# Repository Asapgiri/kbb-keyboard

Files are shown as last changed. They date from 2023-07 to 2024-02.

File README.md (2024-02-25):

# Keyboard by KBB

## Summary
We are making this keyboard for self improvement and fun. The 65% mechanical keyboard has it's original PCB design, case and plate model.

## To open the shematics and PCB design
The PCB design was created in KiCad, so you can open it in the `kicad/default` folder.

## To run the code
You only need to upload the code once using Arduino IDE.

Keep in mind, that first the Atmega32u4 will need a bootloader, witch is programmed trough the bootloader pins. We had to program it with an Esp32-C3-mini, witches Arduino ISA codes I will upload here under the folder `Esp32-ISA`.

## Dependencies
Place the dependencies into the lib folder.
Desktop Utility:
--> simple_serial_port https://github.com/dmicha16/simple_serial_port/tree/master

## Layout
keyboard-layout
In this image the different colors mean the segmentation of the keys with muxes.
You can currently only see the details in Schematic and the Code files.

## Function keys
### Supported
| Combination | Meaning  | | Combination | Meaning  | | Combination | Meaning  |
| --- | --- | --- | --- | --- | --- | --- | --- |
| FN + 1 | F1 | | FN + 7 | F7 | | FN + INS | PRT SCR  |
| FN + 2 | F2 | | FN + 8 | F8 | | FN + WIN | WIN LOCK |
| FN + 3 | F3 | | FN + 9 | F9 | | FN + -> | FN LOCK  |
| FN + 4 | F4 | | FN + 0 | F10 | | FN + ALT | MENU |
| FN + 5 | F5 | | FN + - | F11 | | FN + ESC | ` |
| FN + 6 | F6 | | FN + = | F12 | | FN + SHIFT + ESC | ~ |

### Under develpement
These keys are yet not supported due to the incompatibility of `Keyboard.h`.
| Combination | Meaning |
| --- | --- |
| FN + ; | PREV MUSIC  |
| FN + \ | NEXT  MUSIC |
| FN + , | VOLUME DOWN |
| FN + . | VOLUME UP |
| FN + / | PLAY |
| FN + END | SLEEP |

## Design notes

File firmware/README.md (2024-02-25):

# Read before building!

Before you can build the project, first you have to install the arduino libraries.

## Run the following command if you are on linux:
```sh
sudo apt install arduino clang lld cmake
sudo snap install arduino-cli
```
if you install `arduino-cli` with a different method, then change the path to `.arduino15` folder in `ARDUINO_PATH`
cmake variable in `toolchain/avr.toolchain.cmake`.

## After installation, run the avr initalization:
```sh
arduino-cli core install arduino:avr --verbose
```

# To build, first initialize the subdirectories, then build the project with cmake
```
git submodule init
```

To build in the `build` directoriy:
```
cmake -S. -Bbuild -D CMAKE_TOOLCHAIN_FILE=toolchain/leonardo.toolchain.cmake
cmake --build build -j -t kbb_keyboard
```

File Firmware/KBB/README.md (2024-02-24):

# Read before building!

Before you can build the project, first you have to install the arduino libraries.

## Run the following command if you are on linux:
```
sudo apt install arduino clang lld cmake
```

## After installation, you need to run the newly installed Arduino IDE to install the basic AVR libraries fro building:

Under `Tools > Board > Board Manager`.

# To build, first initialize the subdirectories, then build the project with cmake
```
git submodule init
```
To build in the `build` directoriy:
```
cmake -S. -Bbuild -D CMAKE_TOOLCHAIN_FILE=Arduino-AVR-CMake/cmake/toolchain/leonardo.toolchain.cmake
cmake --build build -j -t kbb_keyboard
```

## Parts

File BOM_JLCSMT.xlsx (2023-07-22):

Comment | Designator | Footprint | JLCPCB Part #（optional）
5V Zener | D4 | D_SOD-523 | C151368
100nF | C5,C15,C9,C10,C8,C14,C13,C12,C7,C11,C6 | C_0402_1005Metric | C1525
R22 | R8,R7 | R_0402_1005Metric | C409710
220pF | C17,C22,C16,C23,C21,C20,C18,C19 | C_0402_1005Metric | C114401
USB_C_Receptacle_USB2.0 | J1 | USB_C_Receptacle_G-Switch_GT-USB-7010ASV | C5178539
U74HC4051G-Q16 | MUX6,MUX3,MUX1,MUX7,MUX4,MUX2,MUX5,MUX8 | QFN-16-1EP_3x3mm_P0.5mm_EP1.7x1.7mm | C2848707
R10K | R18,R15,R9,R13,R17,R16,R12,R11,R14 | R_0402_1005Metric | C176119
R1M | R6 | R_0603_1608Metric | C2889400
5.11K | R20,R2,R19,R1 | R_0402_1005Metric | C911893
2pF | C2,C3 | C_0402_1005Metric | C147348
1uF | C1 | C_0402_1005Metric | C913556
R330 | R5,R3,R4 | R_0402_1005Metric | C186314
7F16000E09UCG | Y1 | Crystal_SMD_7F16000E09UCG_4pin | C252269
PMOS | Q1 | TO-252-2 | C558296
R100K | R10 | R_0402_1005Metric | C407753
ATmega32U4-M | U1 | QFN-44-1EP_7x7mm_P0.5mm_EP5.2x5.2mm | C112161
10uF | C4 | C_0402_1005Metric | C466623
PG151101S11 | S48,S6,S21,S31,S51,S20,S65,S2,S26,S64,S12,S27,S46,S18,S43,S47,S63,S62,S9,S40,S34,S19,S25,S30,S23,S5,S37,S17,S60,S36,S49,S3,S11,S7,S45,S44,S38,S1,S67,S39,S50,S33,S61,S16,S10,S22,S4,S35,S24,S52,S66,S32,S13,S8 | SW_Cherry_MX_1.00u_PCB | C400239
PG151101S12 | S57 | SW_Cherry_MX_6.25u_PCB | C400239
PG151101S13 | S54,S59,S58,S55,S56 | SW_Cherry_MX_1.25u_PCB | C400239
PG151101S14 | S14 | SW_Cherry_MX_2.00u_PCB | C400239
PG151101S15 | S42,S41 | SW_Cherry_MX_2.25u_PCB | C400239
PG151101S16 | S15,S28 | SW_Cherry_MX_1.50u_PCB | C400239
PG151101S17 | S29,S53 | SW_Cherry_MX_1.75u_PCB | C400239

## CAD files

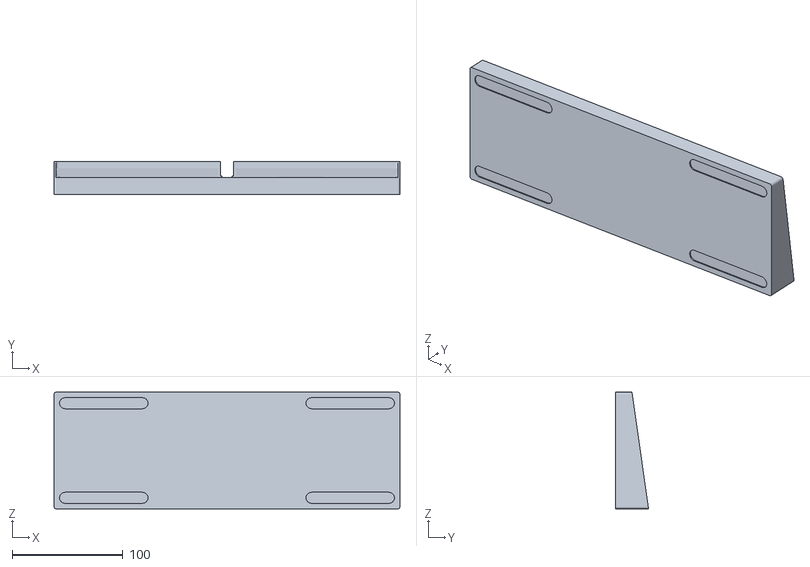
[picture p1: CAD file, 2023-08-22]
case_design/Inventor/stl/case_in_one_full_remake.stl
312.9 x 30.0 x 105.5

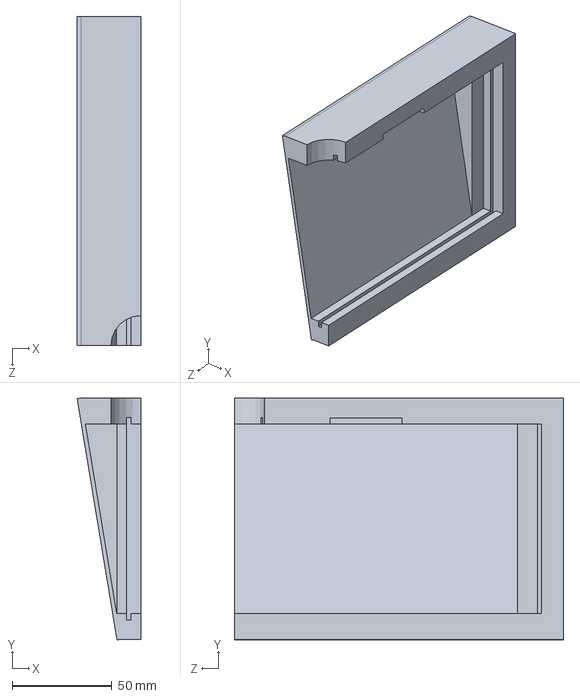
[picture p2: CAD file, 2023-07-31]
case_design/SBVersions/Beta 0.9/KBB_Keyboard right.SLDPRT
32.0 x 121.3 x 165.0 mm

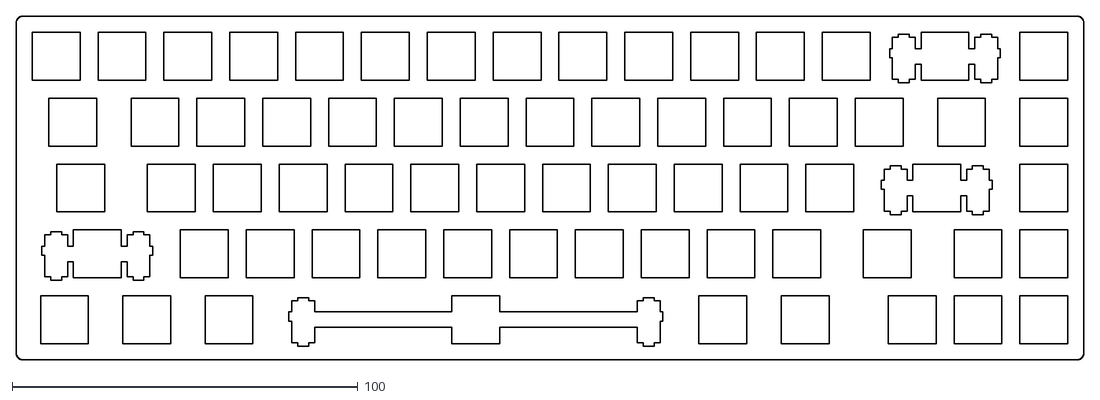
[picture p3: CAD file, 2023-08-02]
plate/plate.dxf
309.0 x 99.4

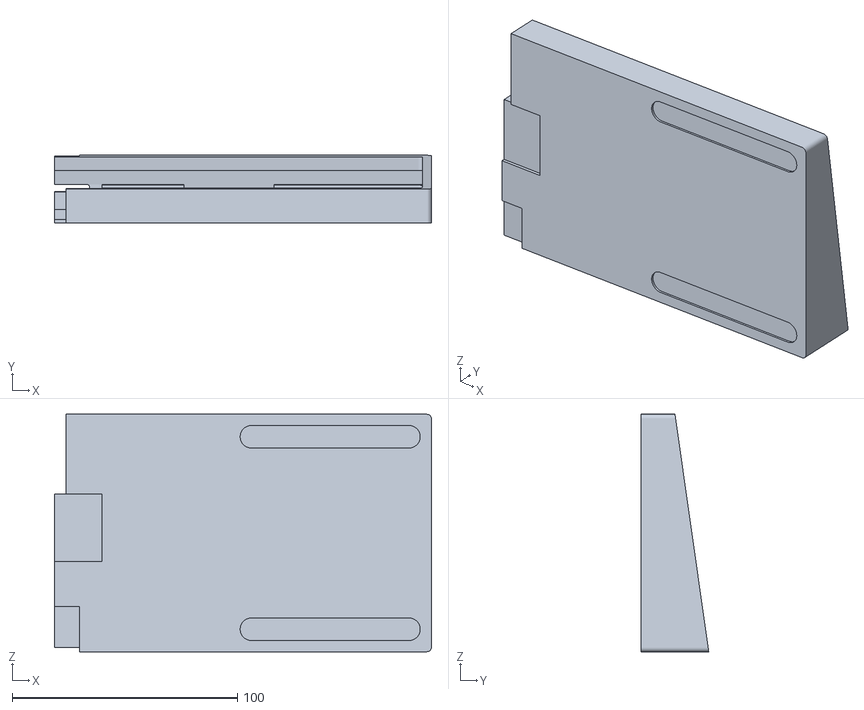
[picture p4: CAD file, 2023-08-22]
case_design/Inventor/stl/case_in_one_p2.stl
167.4 x 30.0 x 105.5

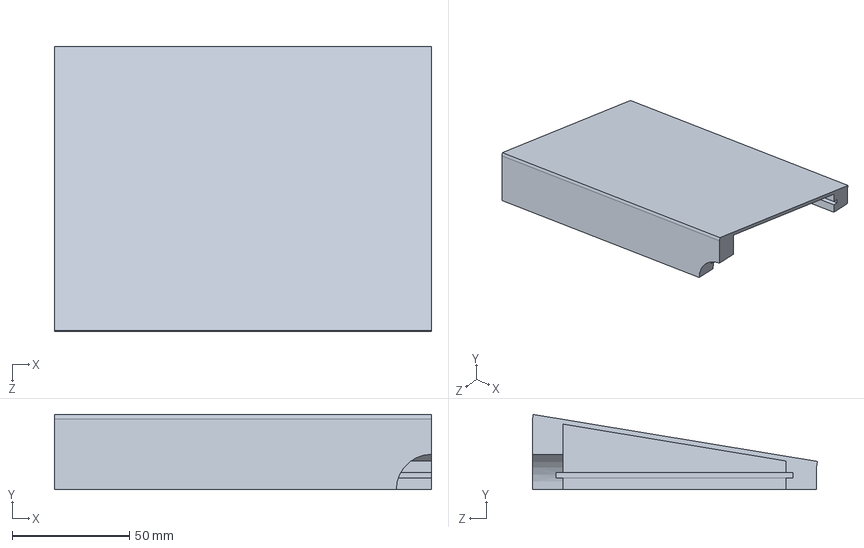
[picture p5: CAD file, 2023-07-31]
case_design/SBVersions/Beta 0.9/KBB_Keyboard left.SLDPRT
160.5 x 32.0 x 121.3 mm

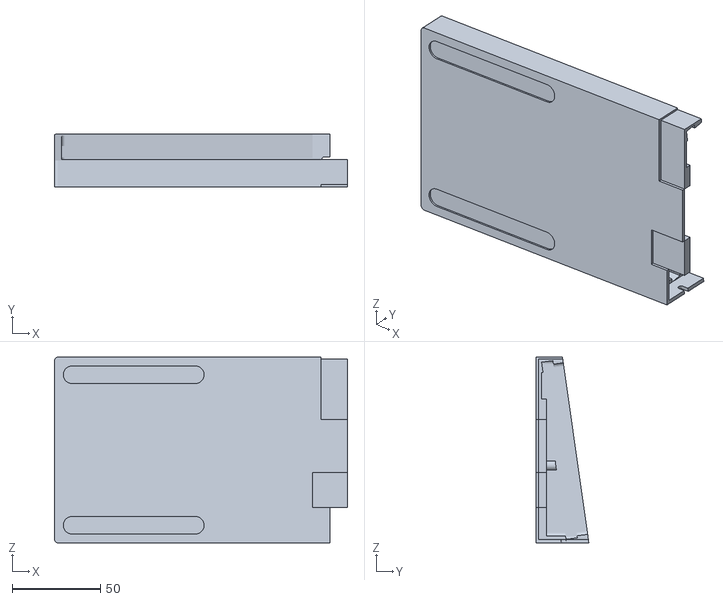
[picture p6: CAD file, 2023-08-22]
case_design/Inventor/stl/case_in_one_p1.stl
166.4 x 30.0 x 105.5

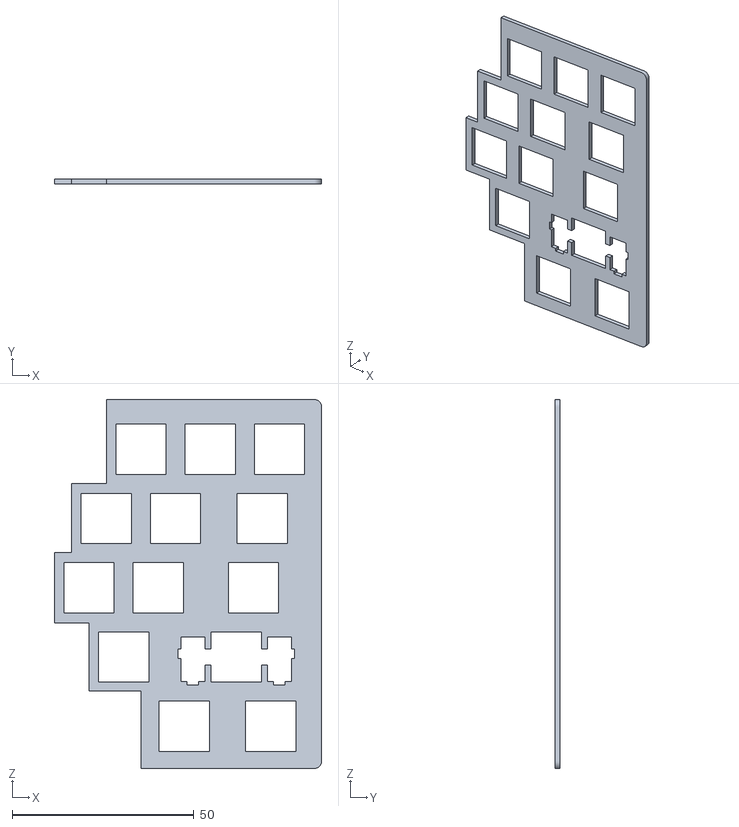
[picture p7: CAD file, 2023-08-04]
case_design/Inventor/stl/case_plate_p3.stl
73.5 x 1.40 x 101.5

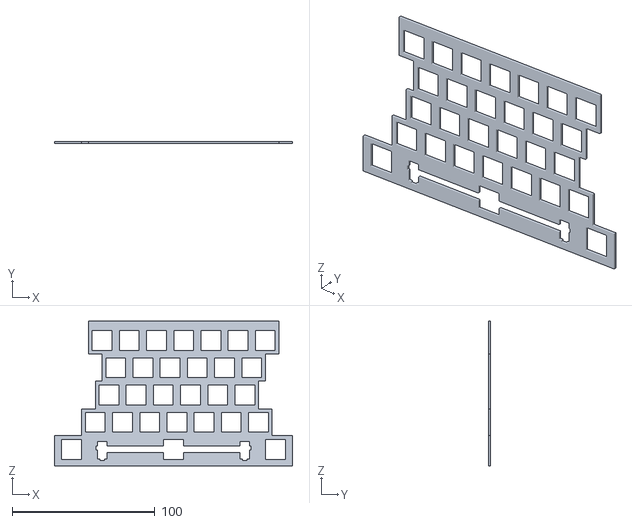
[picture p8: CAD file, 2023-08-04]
case_design/Inventor/stl/case_plate_p1.stl
166.7 x 1.40 x 101.5

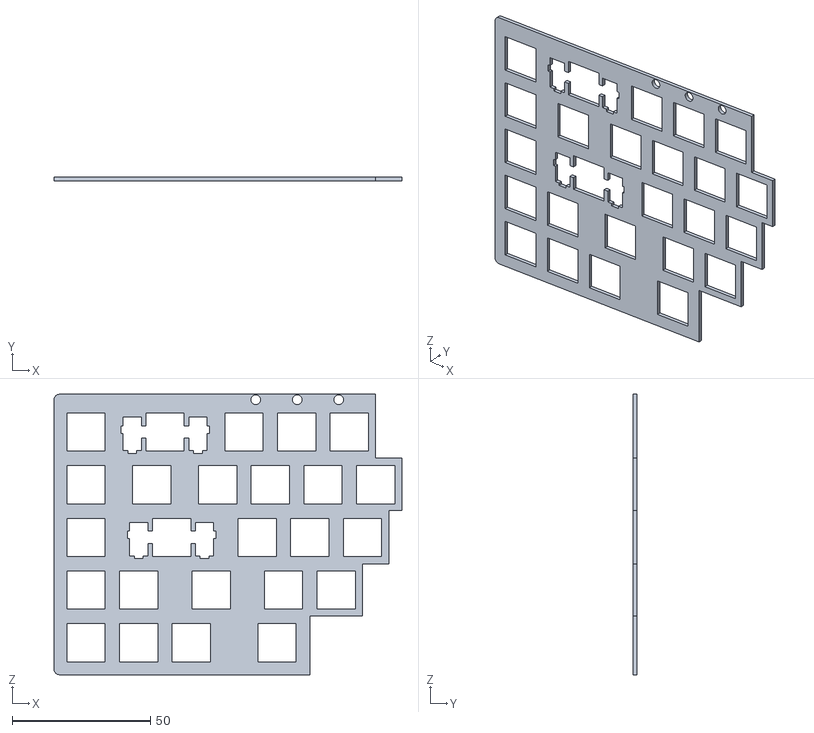
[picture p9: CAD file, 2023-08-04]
case_design/Inventor/stl/case_plate_p2.stl
125.9 x 1.40 x 101.5

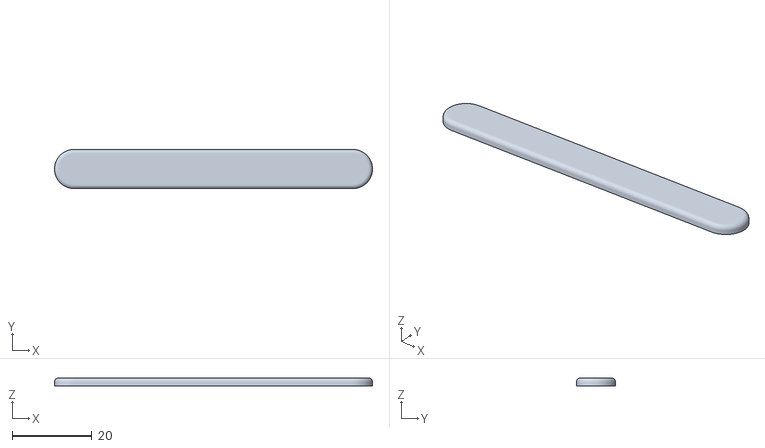
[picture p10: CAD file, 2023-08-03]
case_design/Inventor/stl/foot.stl
79.6 x 9.80 x 2.00

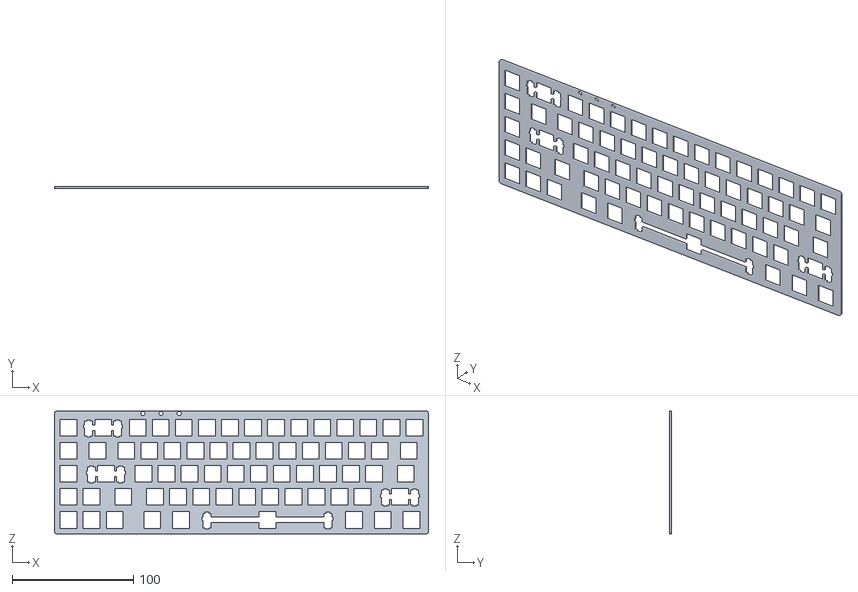
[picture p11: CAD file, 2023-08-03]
case_design/Inventor/stl/case_plate.stl
309.0 x 1.48 x 101.5

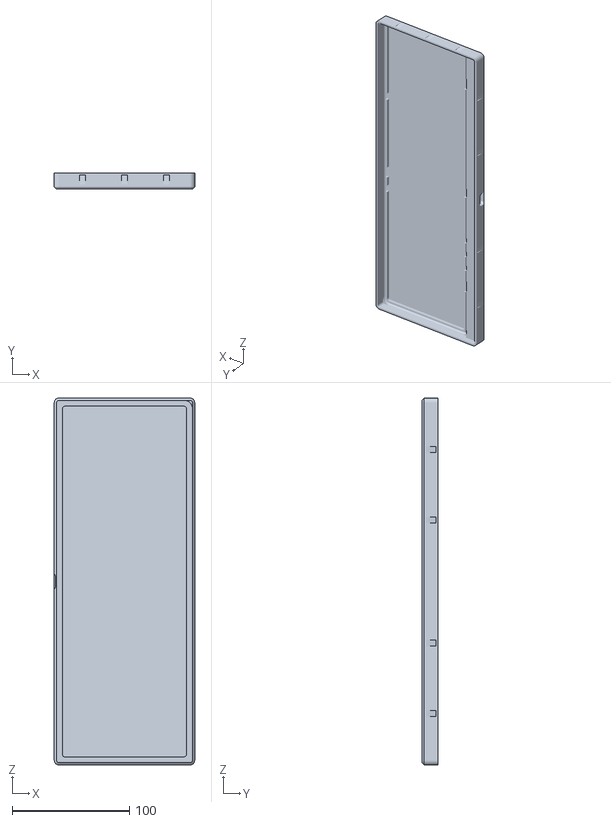
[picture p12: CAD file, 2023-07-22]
case_design/Inventor/stl/case bottom.stl
120.0 x 14.0 x 313.3

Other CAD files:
case_design/Inventor/stl/case_in_one_p2_no_holder.stl
case_design/Inventor/stl/case_in_one_p1_no_holder.stl
case_design/Inventor/stl/case_in_one.stl
case_design/Inventor/OldVersions/case_in_one.0004.ipt
case_design/Inventor/OldVersions/case_plate.0003.ipt
case_design/Inventor/OldVersions/case_plate_p1.0006.ipt
case_design/Inventor/OldVersions/case_plate_p2.0001.ipt
case_design/Inventor/OldVersions/case_plate_p2.0002.ipt
case_design/Inventor/case bottom display.ipt
case_design/Inventor/case bottom.ipt
case_design/Inventor/case top display.ipt
case_design/Inventor/case top.ipt
case_design/Inventor/case_in_one.ipt
case_design/Inventor/case_in_one_full_remake.ipt
case_design/Inventor/case_in_one_p1.ipt
case_design/Inventor/case_in_one_p2.ipt
case_design/Inventor/case_plate.ipt
case_design/Inventor/case_plate_p1.ipt
case_design/Inventor/case_plate_p2.ipt
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

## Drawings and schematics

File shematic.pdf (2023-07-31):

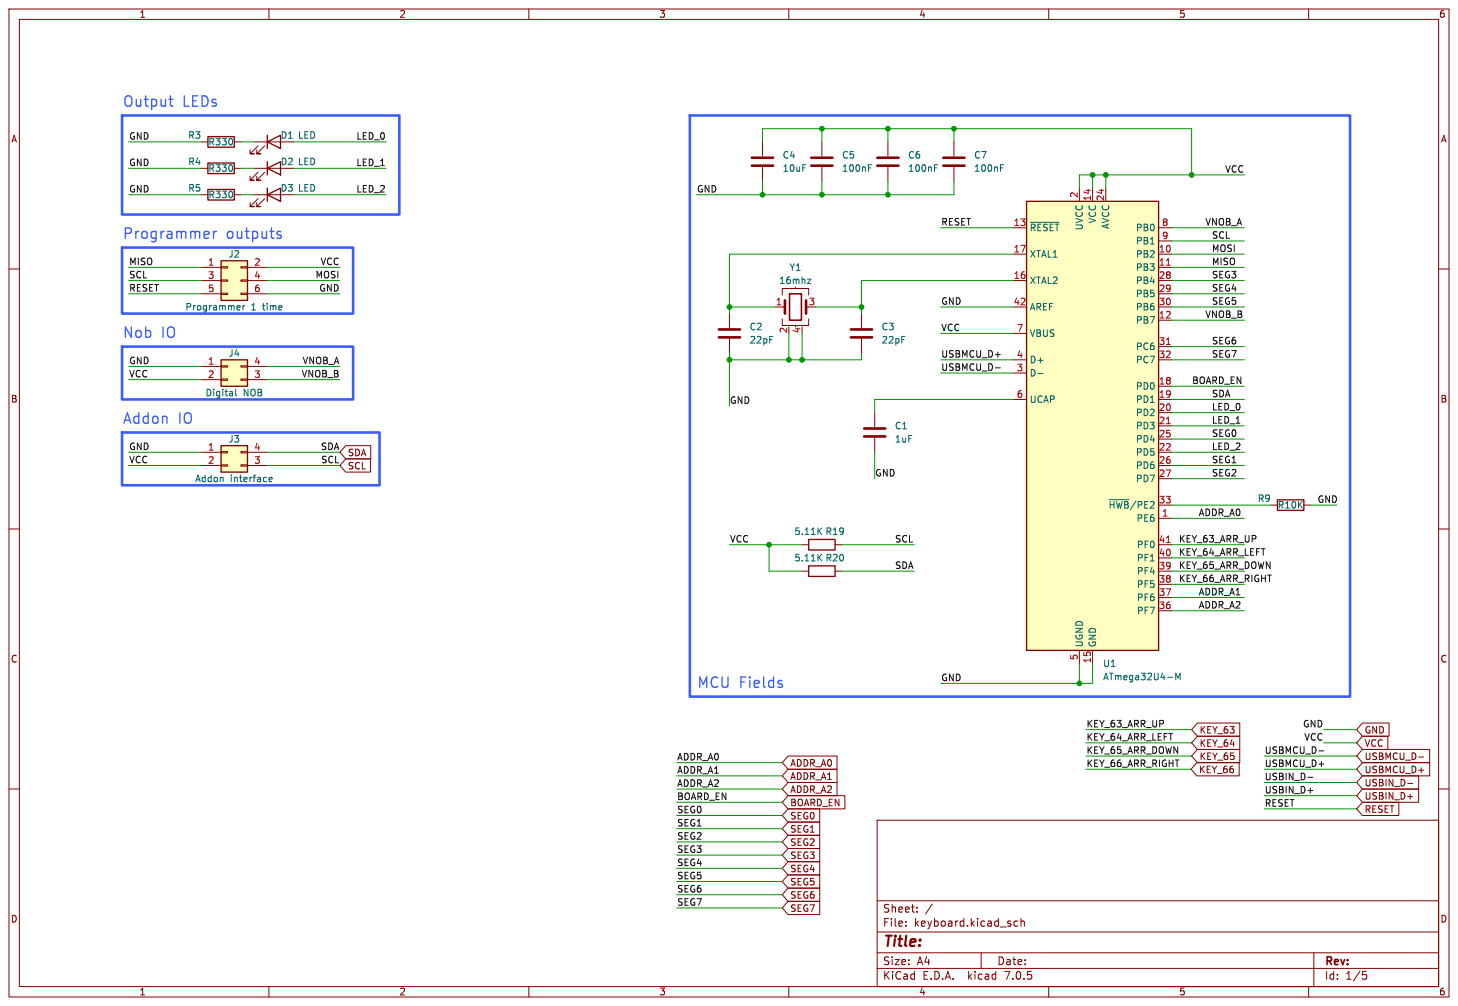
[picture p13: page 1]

Id: 1/5 Title: File: keyboard.kicad_sch Sheet: /

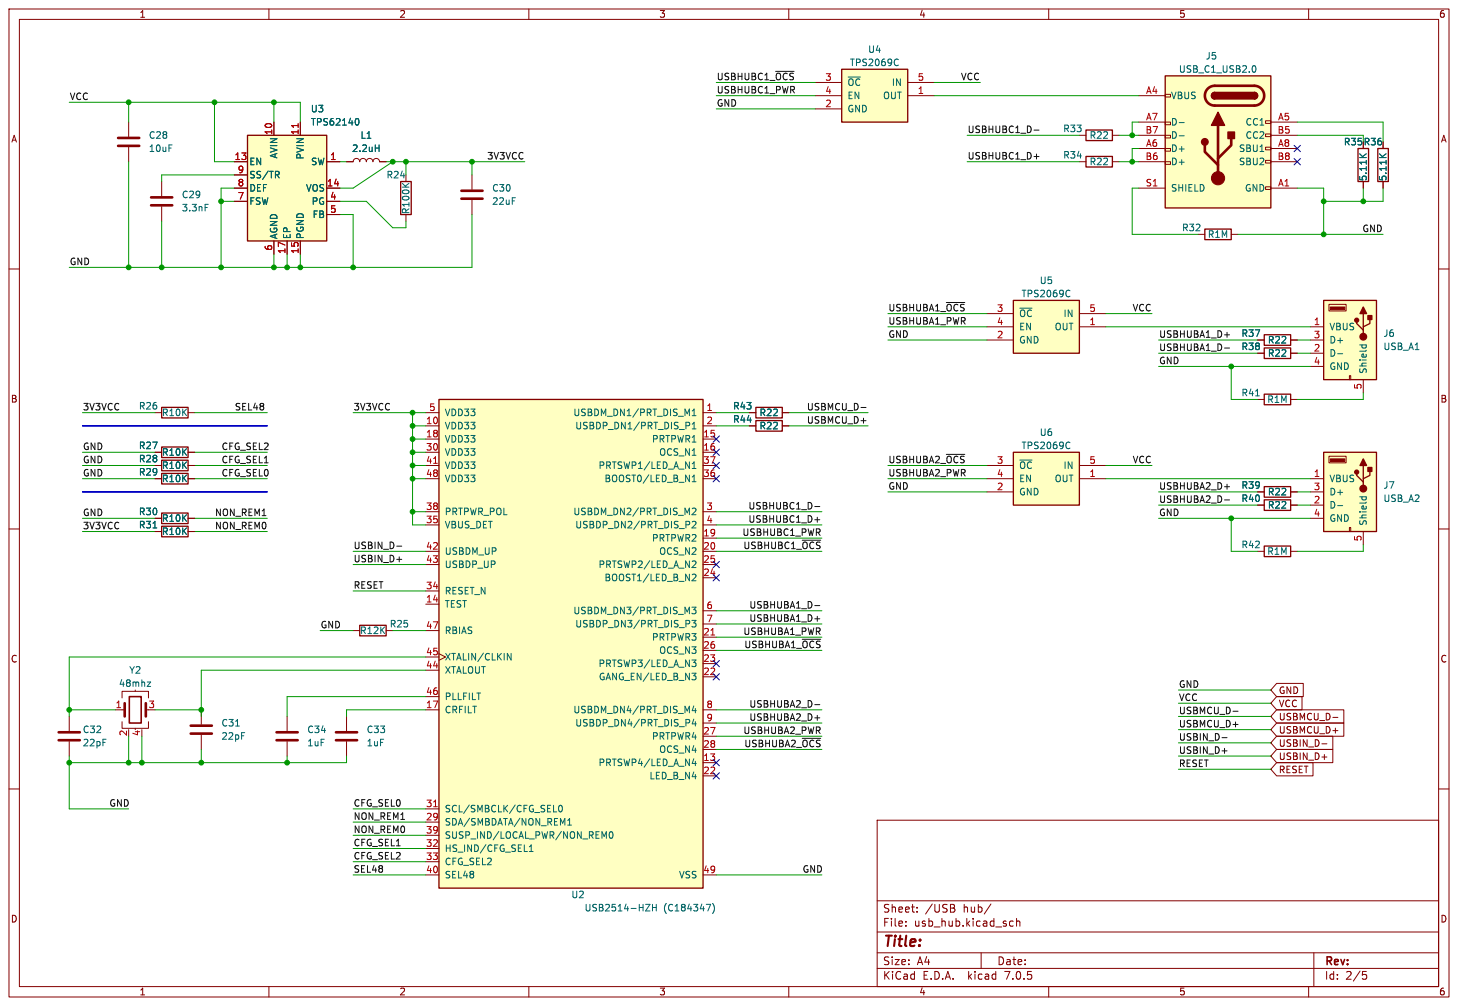
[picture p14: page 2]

6 FSW 7 DEF 8 SS/TR 9 U3 TPS62140 R35 5.11K

6 FSW 7 DEF 8 SS/TR 9 R43 R22

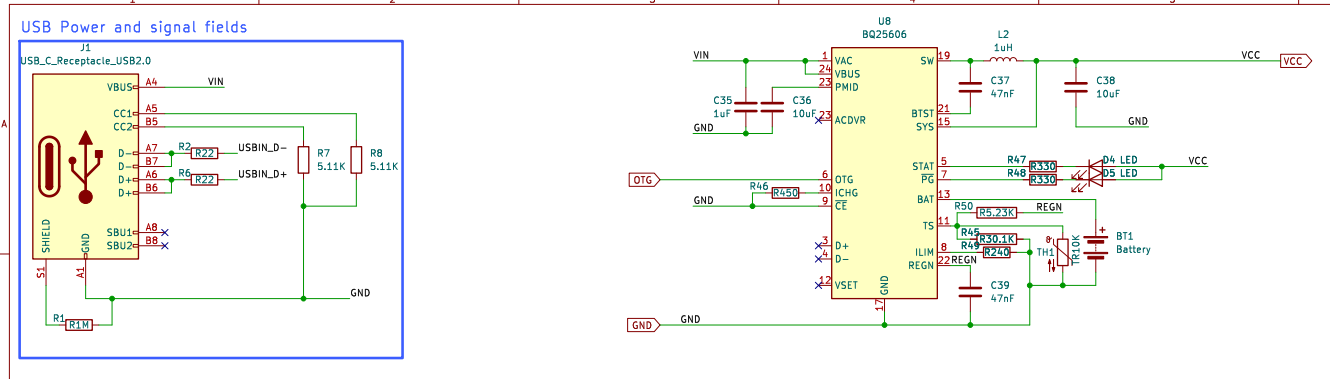
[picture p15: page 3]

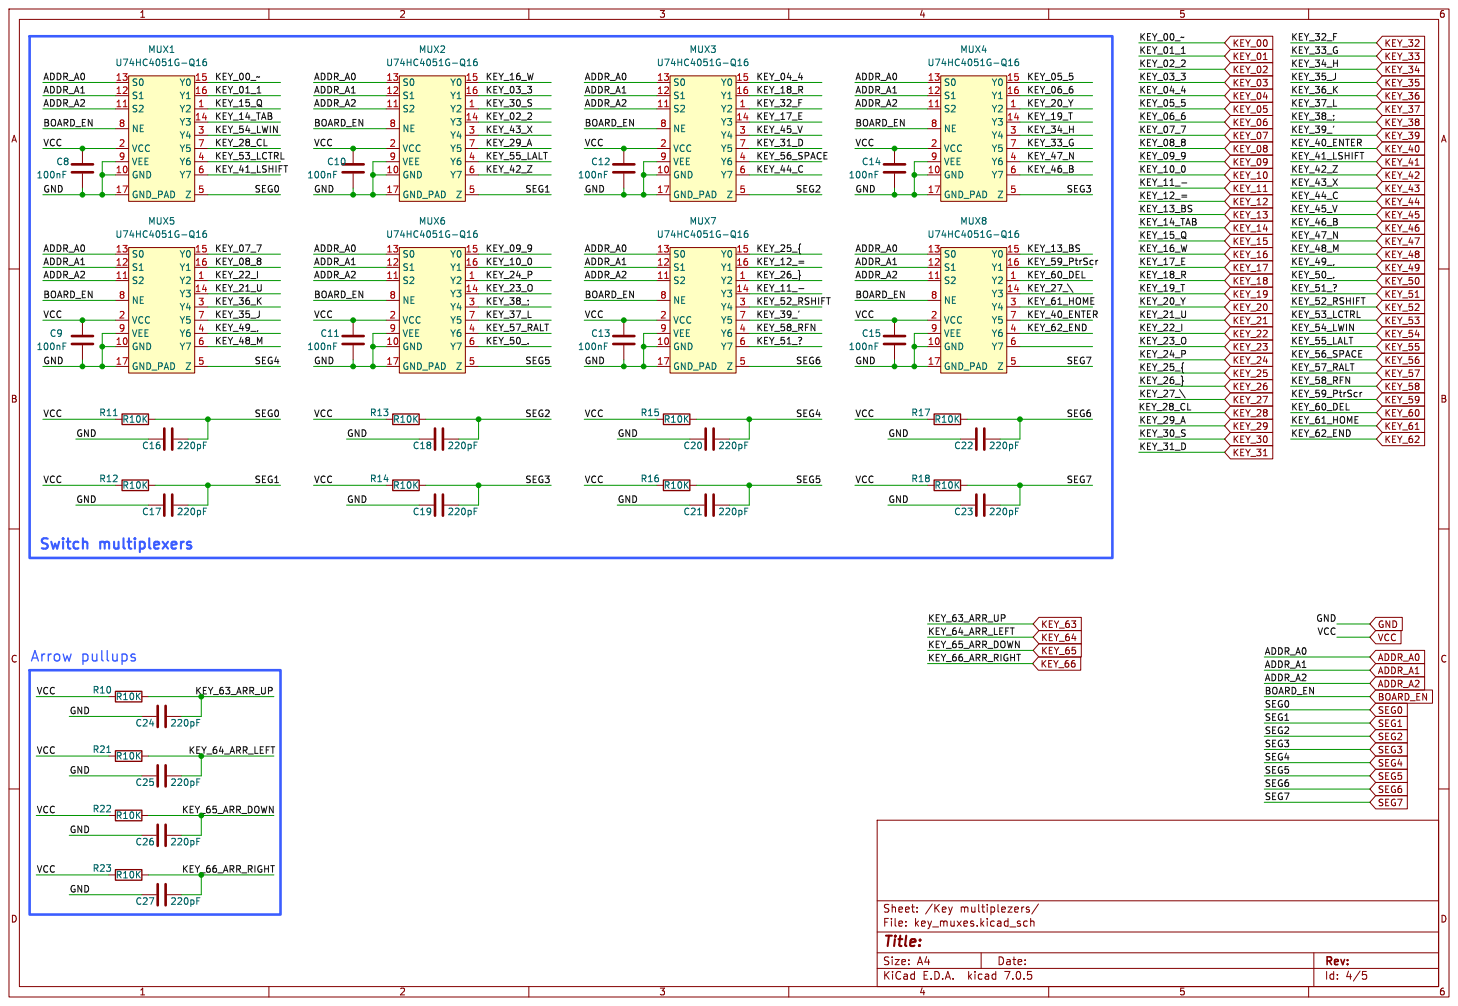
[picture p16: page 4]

Id: 4/5 Title: File: key_muxes.kicad_sch Sheet: /Key multiplezers/

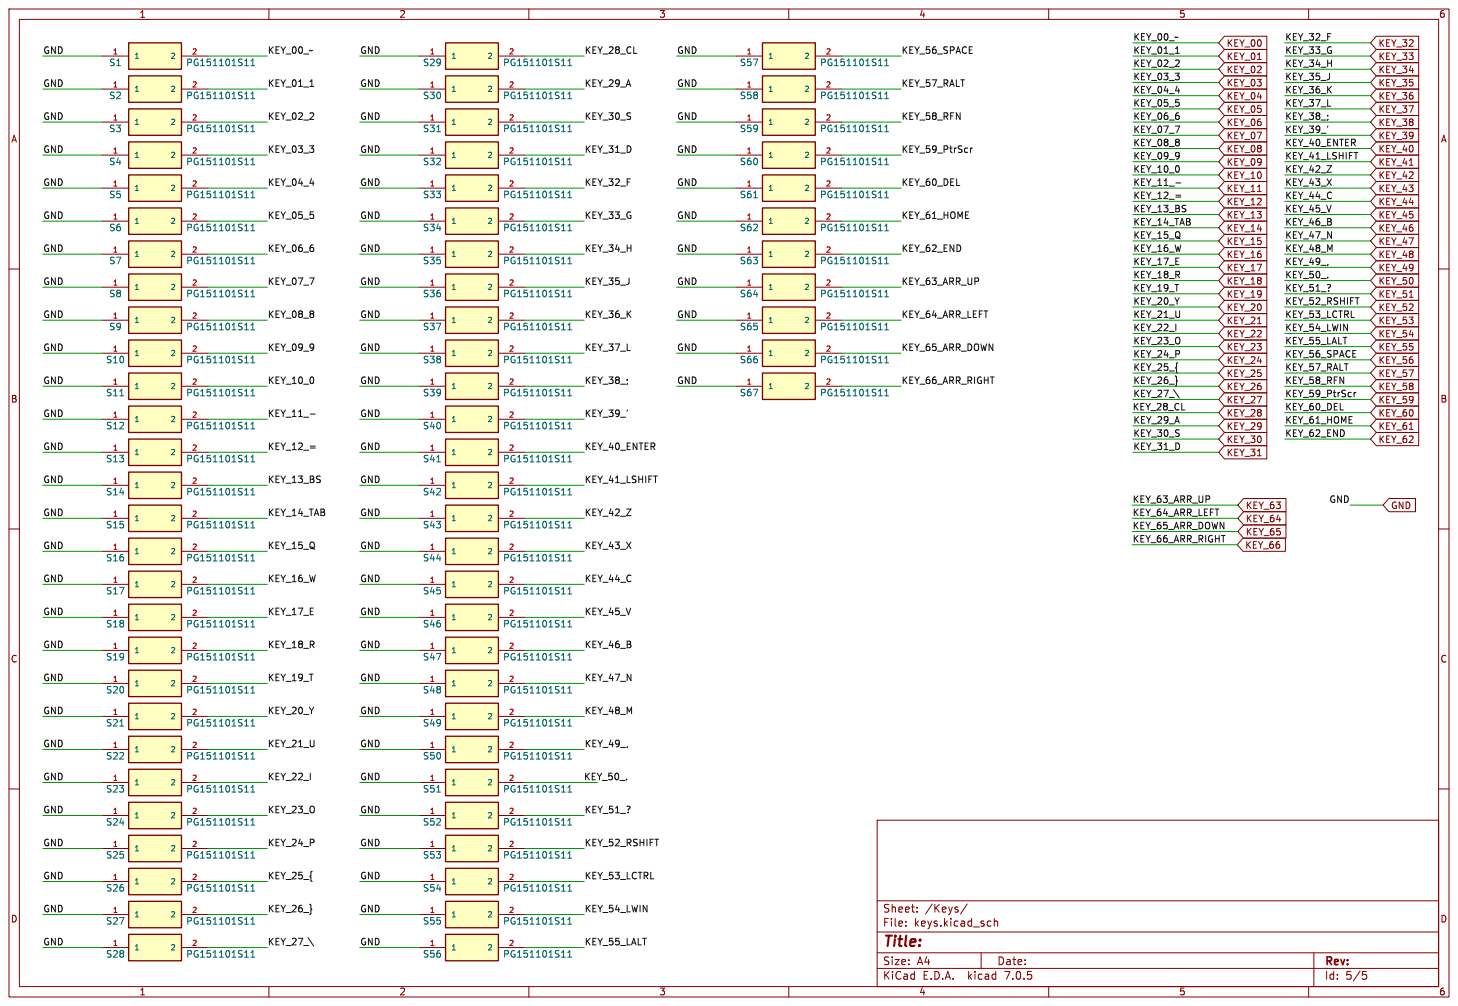
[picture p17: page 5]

GND GND GND GND GND

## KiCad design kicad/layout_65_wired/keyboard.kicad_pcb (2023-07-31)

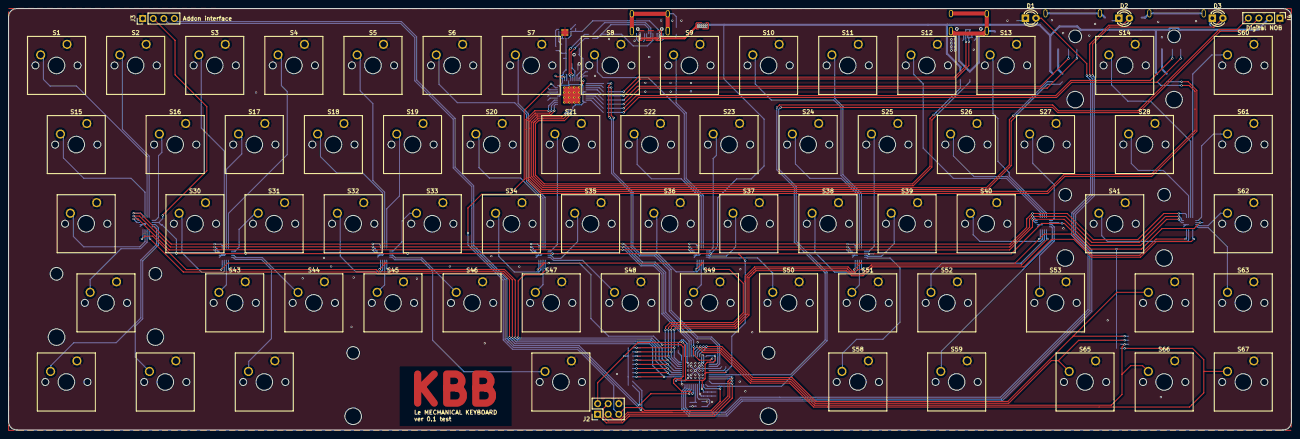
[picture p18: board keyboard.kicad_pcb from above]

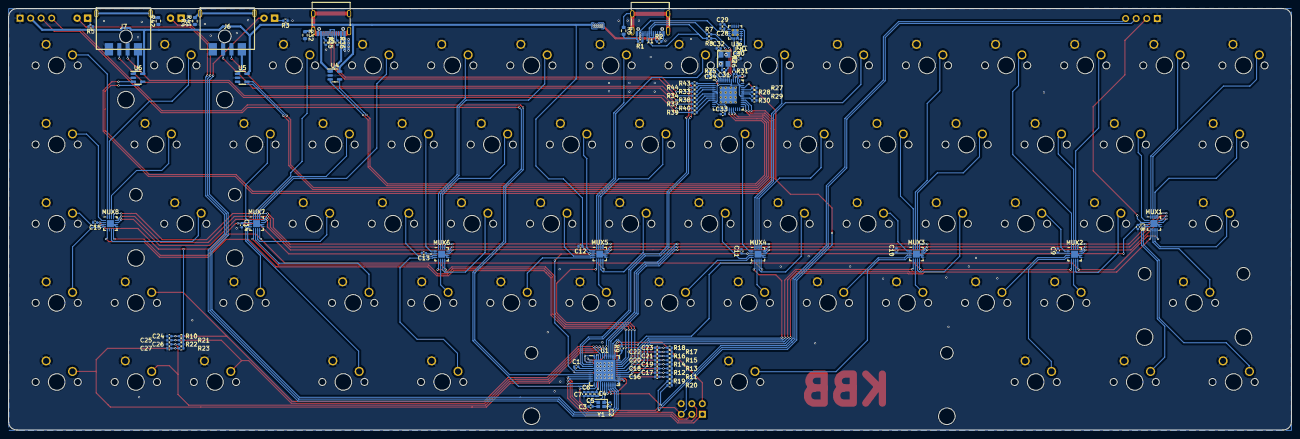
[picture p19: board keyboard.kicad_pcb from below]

Board: 2 copper layers, 308.9 x 101.5 mm, 172 parts (99 on the bottom side), 147 nets.

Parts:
C1, C33, C34: 1uF; C_0402_1005Metric
C2, C3, C31, C32: 22pF; C_0402_1005Metric
C4, C28: 10uF; C_0402_1005Metric
C5, C6, C7, C8, C9, C10, C11, C12, C13, C14, C15: 100nF; C_0402_1005Metric
C16, C17, C18, C19, C20, C21, C22, C23, C24, C25, C26, C27: 220pF; C_0402_1005Metric
C29: 3.3nF; C_0402_1005Metric
C30: 22uF; C_0402_1005Metric
D1, D2, D3: LED; LED_D3.0mm_Clear
J1: USB_C_Receptacle_USB2.0; USB_C_Receptacle_G-Switch_GT-USB-7010ASV
J2: Programmer 1 time; PinHeader_2x03_P2.54mm_Vertical
J3: Addon interface; PinHeader_1x04_P2.54mm_Vertical
J4: Digital NOB; PinHeader_1x04_P2.54mm_Vertical
J5: USB_C1_USB2.0; USB_C_Receptacle_G-Switch_GT-USB-7010ASV
J6: USB_A1; GT_USBA
J7: USB_A2; GT_USBA
L1: 2.2uH; L_0805_2012Metric
MUX1, MUX2, MUX3, MUX4, MUX5, MUX6, MUX7, MUX8: U74HC4051G-Q16; QFN-16-1EP_3x3mm_P0.5mm_EP1.7x1.7mm
R1, R2, R19, R20, R35, R36: 5.11K; R_0402_1005Metric
R3, R4, R5: R330; R_0402_1005Metric
R6, R32, R41, R42: R1M; R_0603_1608Metric
R7, R8, R33, R34, R37, R38, R39, R40, R43, R44: R22; R_0402_1005Metric
R9, R10, R11, R12, R13, R14, R15, R16, R17, R18, R21, R22, R23, R26, R27, R28, R29, R30, R31: R10K; R_0402_1005Metric
R24: R100K; R_0402_1005Metric
R25: R12K; R_0402_1005Metric
S1, S2, S3, S4, S5, S6, S7, S8, S9, S10, S11, S12, S13, S16, S17, S18, S19, S20, S21, S22, S23, S24, S25, S26, S27, S30, S31, S32, S33, S34, S35, S36, S37, S38, S39, S40, S43, S44, S45, S46, S47, S48, S49, S50, S51, S52, S60, S61, S62, S63, S64, S65, S66, S67: PG151101S11; SW_Cherry_MX_1.00u_PCB
S14: PG151101S11; SW_Cherry_MX_2.00u_PCB
S15, S28: PG151101S11; SW_Cherry_MX_1.50u_PCB
S29, S53: PG151101S11; SW_Cherry_MX_1.75u_PCB
S41, S42: PG151101S11; SW_Cherry_MX_2.25u_PCB
S54, S55, S56, S58, S59: PG151101S11; SW_Cherry_MX_1.25u_PCB
S57: PG151101S11; SW_Cherry_MX_6.25u_PCB
U1: ATmega32U4-M; QFN-44-1EP_7x7mm_P0.5mm_EP5.2x5.2mm
U2: USB2514-HZH (C184347); VQFN-48-1EP_7x7mm_P0.5mm_EP4.1x4.1mm_ThermalVias
U3: TPS62140; VQFN-16-1EP_3x3mm_P0.5mm_EP1.68x1.68mm_ThermalVias
U4, U5, U6: TPS2069C; SOT-23-5
Y1: 16mhz; Crystal_SMD_7F16000E09UCG_4pin
Y2: 48mhz; Crystal_SMD_TXC_7M-4Pin_3.2x2.5mm

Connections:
/LED_0: D1.2 (A), U1.20 (PD2)
/LED_1: D2.2 (A), U1.21 (PD3)
/LED_2: D3.2 (A), U1.22 (PD5)
/MISO: J2.1, U1.11 (PB3)
/MOSI: J2.4, U1.10 (PB2)
/USB hub/3V3VCC: C30.1, L1.2, R24.1, R26.1, R31.1, U2.5 (VDD33), U2.10 (VDD33), U2.18 (VDD33), U2.30 (VDD33), U2.35 (VBUS_DET), U2.38 (PRTPWR_POL), U2.41 (VDD33), U2.48 (VDD33), U3.14 (VOS)
/USB hub/CFG_SEL0: R29.2, U2.31 (SCL/SMBCLK/CFG_SEL0)
/USB hub/CFG_SEL1: R28.2, U2.32 (HS_IND/CFG_SEL1)
/USB hub/CFG_SEL2: R27.2, U2.33 (CFG_SEL2)
/USB hub/NON_REM0: R31.2, U2.39 (SUSP_IND/LOCAL_PWR/NON_REM0)
/USB hub/NON_REM1: R30.2, U2.29 (SDA/SMBDATA/NON_REM1)
/USB hub/SEL48: R26.2, U2.40 (SEL48)
/USB hub/USBHUBA1_D+: R37.1, U2.7 (USBDP_DN3/PRT_DIS_P3)
/USB hub/USBHUBA1_D-: R38.1, U2.6 (USBDM_DN3/PRT_DIS_M3)
/USB hub/USBHUBA1_PWR: U2.21 (PRTPWR3), U5.4 (EN)
/USB hub/USBHUBA1_~OCS: U2.26 (OCS_N3), U5.3 (~OC)
/USB hub/USBHUBA2_D+: R39.1, U2.9 (USBDP_DN4/PRT_DIS_P4)
/USB hub/USBHUBA2_D-: R40.1, U2.8 (USBDM_DN4/PRT_DIS_M4)
/USB hub/USBHUBA2_PWR: U2.27 (PRTPWR4), U6.4 (EN)
/USB hub/USBHUBA2_~OCS: U2.28 (OCS_N4), U6.3 (~OC)
/USB hub/USBHUBC1_D+: R34.1, U2.4 (USBDP_DN2/PRT_DIS_P2)
/USB hub/USBHUBC1_D-: R33.1, U2.3 (USBDM_DN2/PRT_DIS_M2)
/USB hub/USBHUBC1_PWR: U2.19 (PRTPWR2), U4.4 (EN)
/USB hub/USBHUBC1_~OCS: U2.20 (OCS_N2), U4.3 (~OC)
/VNOB_A: J4.4, U1.8 (PB0)
/VNOB_B: J4.3, U1.12 (PB7)
ADDR_A0: MUX1.13 (S0), MUX2.13 (S0), MUX3.13 (S0), MUX4.13 (S0), MUX5.13 (S0), MUX6.13 (S0), MUX7.13 (S0), MUX8.13 (S0), U1.1 (PE6)
ADDR_A1: MUX1.12 (S1), MUX2.12 (S1), MUX3.12 (S1), MUX4.12 (S1), MUX5.12 (S1), MUX6.12 (S1), MUX7.12 (S1), MUX8.12 (S1), U1.37 (PF6)
ADDR_A2: MUX1.11 (S2), MUX2.11 (S2), MUX3.11 (S2), MUX4.11 (S2), MUX5.11 (S2), MUX6.11 (S2), MUX7.11 (S2), MUX8.11 (S2), U1.36 (PF7)
BOARD_EN: MUX1.8 (NE), MUX2.8 (NE), MUX3.8 (NE), MUX4.8 (NE), MUX5.8 (NE), MUX6.8 (NE), MUX7.8 (NE), MUX8.8 (NE), U1.18 (PD0)
GND: C1.2, C2.2, C3.2, C4.2, C5.2, C6.2, C7.2, C8.2, C9.2, C10.2, C11.2, C12.2, C13.2, C14.2, C15.2, C16.1, C17.1, C18.1, C19.1, C20.1, C21.1, C22.1, C23.1, C24.1, C25.1, C26.1, C27.1, C28.2, C29.2, C30.2, C31.2, C32.2, C33.2, C34.2, J1.A1 (GND), J1.A12 (GND), J1.B1 (GND), J1.B12 (GND), J2.6, J3.1, J4.1, J5.A1 (GND), J5.A12 (GND), J5.B1 (GND), J5.B12 (GND), J6.4 (GND), J7.4 (GND), MUX1.9 (VEE), MUX1.10 (GND), MUX1.17 (GND_PAD), MUX2.9 (VEE), MUX2.10 (GND), MUX2.17 (GND_PAD), MUX3.9 (VEE), MUX3.10 (GND), MUX3.17 (GND_PAD), MUX4.9 (VEE), MUX4.10 (GND), MUX4.17 (GND_PAD), MUX5.9 (VEE), MUX5.10 (GND), MUX5.17 (GND_PAD), MUX6.9 (VEE), MUX6.10 (GND), MUX6.17 (GND_PAD), MUX7.9 (VEE), MUX7.10 (GND), MUX7.17 (GND_PAD), MUX8.9 (VEE), MUX8.10 (GND), MUX8.17 (GND_PAD), R1.2, R2.2, R3.1, R4.1, R5.1, R6.2, R9.2, R25.1, R27.1, R28.1, R29.1, R30.1, R32.2, R35.2, R36.2, R41.1, R42.1, S1.1, S2.1, S3.1, S4.1, S5.1, S6.1, S7.1, S8.1, S9.1, S10.1, S11.1, S12.1, S13.1, S14.1, S15.1, S16.1, S17.1, S18.1, S19.1, S20.1, S21.1, S22.1, S23.1, S24.1, S25.1, S26.1, S27.1, S28.1, S29.1, S30.1, S31.1, S32.1, S33.1, S34.1, S35.1, S36.1, S37.1, S38.1, S39.1, S40.1, S41.1, S42.1, S43.1, S44.1, S45.1, S46.1, S47.1, S48.1, S49.1, S50.1, S51.1, S52.1, S53.1, S54.1, S55.1, S56.1, S57.1, S58.1, S59.1, S60.1, S61.1, S62.1, S63.1, S64.1, S65.1, S66.1, S67.1, U1.5 (UGND), U1.15 (GND), U1.23 (GND), U1.35 (GND), U1.42 (AREF), U1.43 (GND), U1.45 (GND), U2.49 (VSS), U3.5 (FB), U3.6 (AGND), U3.7 (FSW), U3.8 (DEF), U3.15 (PGND), U3.16 (PGND), U3.17 (EP), U4.2 (GND), U5.2 (GND), U6.2 (GND), Y1.2, Y1.4, Y2.2, Y2.4
KEY_00: MUX1.15 (Y0), S1.2
KEY_01: MUX1.16 (Y1), S2.2
KEY_02: MUX2.14 (Y3), S3.2
KEY_03: MUX2.16 (Y1), S4.2
KEY_04: MUX3.15 (Y0), S5.2
KEY_05: MUX4.15 (Y0), S6.2
KEY_06: MUX4.16 (Y1), S7.2
KEY_07: MUX5.15 (Y0), S8.2
KEY_08: MUX5.16 (Y1), S9.2
KEY_09: MUX6.15 (Y0), S10.2
KEY_10: MUX6.16 (Y1), S11.2
KEY_11: MUX7.14 (Y3), S12.2
KEY_12: MUX7.16 (Y1), S13.2
KEY_13: MUX8.15 (Y0), S14.2
KEY_14: MUX1.14 (Y3), S15.2
KEY_15: MUX1.1 (Y2), S16.2
KEY_16: MUX2.15 (Y0), S17.2
KEY_17: MUX3.14 (Y3), S18.2
KEY_18: MUX3.16 (Y1), S19.2
KEY_19: MUX4.14 (Y3), S20.2
KEY_20: MUX4.1 (Y2), S21.2
KEY_21: MUX5.14 (Y3), S22.2
KEY_22: MUX5.1 (Y2), S23.2
KEY_23: MUX6.14 (Y3), S24.2
KEY_24: MUX6.1 (Y2), S25.2
KEY_25: MUX7.15 (Y0), S26.2
KEY_26: MUX7.1 (Y2), S27.2
KEY_27: MUX8.14 (Y3), S28.2
KEY_29: MUX2.7 (Y5), S30.2
KEY_30: MUX2.1 (Y2), S31.2
KEY_31: MUX3.7 (Y5), S32.2
KEY_32: MUX3.1 (Y2), S33.2
KEY_33: MUX4.7 (Y5), S34.2
KEY_34: MUX4.3 (Y4), S35.2
KEY_35: MUX5.7 (Y5), S36.2
KEY_36: MUX5.3 (Y4), S37.2
KEY_37: MUX6.7 (Y5), S38.2
KEY_38: MUX6.3 (Y4), S39.2
KEY_39: MUX7.7 (Y5), S40.2
KEY_40: MUX8.7 (Y5), S41.2
KEY_41: MUX1.6 (Y7), S42.2
KEY_42: MUX2.6 (Y7), S43.2
KEY_43: MUX2.3 (Y4), S44.2
KEY_44: MUX3.6 (Y7), S45.2
KEY_45: MUX3.3 (Y4), S46.2
KEY_46: MUX4.6 (Y7), S47.2
KEY_47: MUX4.4 (Y6), S48.2
KEY_48: MUX5.6 (Y7), S49.2
KEY_49: MUX5.4 (Y6), S50.2
KEY_50: MUX6.6 (Y7), S51.2
KEY_51: MUX7.6 (Y7), S52.2
KEY_52: MUX7.3 (Y4), S53.2
KEY_53: MUX1.4 (Y6), S54.2
KEY_54: MUX1.3 (Y4), S55.2
KEY_55: MUX2.4 (Y6), S56.2
KEY_56: MUX3.4 (Y6), S57.2
KEY_57: MUX6.4 (Y6), S58.2
KEY_58: MUX7.4 (Y6), S59.2
KEY_59: MUX8.16 (Y1), S60.2
KEY_60: MUX8.1 (Y2), S61.2
KEY_61: MUX8.3 (Y4), S62.2
KEY_62: MUX8.4 (Y6), S63.2
KEY_63: C24.2, R10.2, S64.2, U1.41 (PF0)
KEY_64: C25.2, R21.2, S65.2, U1.40 (PF1)
KEY_65: C26.2, R22.2, S66.2, U1.39 (PF4)
KEY_66: C27.2, R23.2, S67.2, U1.38 (PF5)
unnamed: D1.1 (K), R3.2
unnamed: D2.1 (K), R4.2
unnamed: D3.1 (K), R5.2
unnamed: J1.A5 (CC1), R2.1
unnamed: J1.B5 (CC2), R1.1
unnamed: J1.A6 (D+), J1.B6 (D+), R8.1
unnamed: J1.A7 (D-), J1.B7 (D-), R7.1
unnamed: J1.S1 (SHIELD), R6.1
unnamed: J5.A5 (CC1), R36.1
unnamed: J5.B5 (CC2), R35.1
unnamed: J5.A6 (D+), J5.B6 (D+), R34.2
unnamed: J5.A7 (D-), J5.B7 (D-), R33.2
unnamed: J5.S1 (SHIELD), R32.1
unnamed: J6.3 (D+), R37.2
unnamed: J6.2 (D-), R38.2
unnamed: J6.5 (Shield), R41.2
unnamed: J6.1 (VBUS), U5.1 (OUT)
unnamed: J7.3 (D+), R39.2
unnamed: J7.2 (D-), R40.2
unnamed: J7.5 (Shield), R42.2
unnamed: J7.1 (VBUS), U6.1 (OUT)
unnamed: L1.1, U3.1 (SW), U3.2 (SW), U3.3 (SW)
unnamed: C1.1, U1.6 (UCAP)
unnamed: C2.1, U1.17 (XTAL1), Y1.1
unnamed: C3.1, U1.16 (XTAL2), Y1.3
unnamed: R9.1, U1.33 (~HWB/PE2)
unnamed: C33.1, U2.17 (CRFILT)
unnamed: C34.1, U2.46 (PLLFILT)
unnamed: R25.2, U2.47 (RBIAS)
unnamed: R43.1, U2.1 (USBDM_DN1/PRT_DIS_M1)
unnamed: R44.1, U2.2 (USBDP_DN1/PRT_DIS_P1)
unnamed: C32.1, U2.45 (XTALIN/CLKIN), Y2.1
unnamed: C31.1, U2.44 (XTALOUT), Y2.3
unnamed: R24.2, U3.4 (PG)
unnamed: C29.1, U3.9 (SS/TR)
unnamed: J5.A4 (VBUS), J5.A9 (VBUS), J5.B4 (VBUS), J5.B9 (VBUS), U4.1 (OUT)
RESET: J2.5, U1.13 (~RESET), U2.34 (RESET_N)
SCL: J2.3, J3.3, R19.2, U1.9 (PB1)
SDA: J3.4, R20.2, U1.19 (PD1)
SEG0: C16.2, MUX1.5 (Z), R11.2, U1.25 (PD4)
SEG1: C17.2, MUX2.5 (Z), R12.2, U1.26 (PD6)
SEG2: C18.2, MUX3.5 (Z), R13.2, U1.27 (PD7)
SEG3: C19.2, MUX4.5 (Z), R14.2, U1.28 (PB4)
SEG4: C20.2, MUX5.5 (Z), R15.2, U1.29 (PB5)
SEG5: C21.2, MUX6.5 (Z), R16.2, U1.30 (PB6)
SEG6: C22.2, MUX7.5 (Z), R17.2, U1.31 (PC6)
SEG7: C23.2, MUX8.5 (Z), R18.2, U1.32 (PC7)
USBMCU_D+: R44.2, U1.4 (D+)
USBMCU_D-: R43.2, U1.3 (D-)
VCC: C4.1, C5.1, C6.1, C7.1, C8.1, C9.1, C10.1, C11.1, C12.1, C13.1, C14.1, C15.1, C28.1, J1.A4 (VBUS), J1.A9 (VBUS), J1.B4 (VBUS), J1.B9 (VBUS), J2.2, J3.2, J4.2, MUX1.2 (VCC), MUX2.2 (VCC), MUX3.2 (VCC), MUX4.2 (VCC), MUX5.2 (VCC), MUX6.2 (VCC), MUX7.2 (VCC), MUX8.2 (VCC), R10.1, R11.1, R12.1, R13.1, R14.1, R15.1, R16.1, R17.1, R18.1, R19.1, R20.1, R21.1, R22.1, R23.1, U1.2 (UVCC), U1.7 (VBUS), U1.14 (VCC), U1.24 (AVCC), U1.34 (VCC), U1.44 (AVCC), U3.10 (AVIN), U3.11 (PVIN), U3.12 (PVIN), U3.13 (EN), U4.5 (IN), U5.5 (IN), U6.5 (IN)

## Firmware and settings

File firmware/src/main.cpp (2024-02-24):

#include "KBB.h"
#include <Keyboard.h>

static KBB* MainInterface = nullptr;
static unsigned char segment = 0;

void setup() {
  Keyboard.begin();
  Keyboard.releaseAll();
  MainInterface = new KBB();
  MainInterface->begin();
}

void loop() {
  MainInterface->ChangeSegment(segment);  //Find the next Target
  MainInterface->RefreshKeyMap();         //Refresh the actually pressed keys map
  if(MainInterface->CompareLastKeys()){   //If it changed
    MainInterface->SendSegment();         //Send the changes to host
    MainInterface->SaveToPastSegment();   //Copy the actual segment to the last
  }
  
  segment++;
}

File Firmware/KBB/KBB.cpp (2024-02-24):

#include "KBB.h"
#include <Arduino.h>
#include <Keyboard.h>
#include <EEPROM.h>

////////////////////////////////////////////////////////////////////////////////////////////////////////////////////
/// Private fields
////////////////////////////////////////////////////////////////////////////////////////////////////////////////////

static bool win_locked = false;
static bool fn_locked = false;
static bool caps_locked = false;


static void key_win_lock_toggle(void) {
  win_locked = !win_locked;
  digitalWrite(PIN_LED_WINLOCK, win_locked);
}

static void key_fn_lock_toggle(void) {
  fn_locked = !fn_locked;
  digitalWrite(PIN_LED_FNLOCK, fn_locked);
}

static void key_caps_lock_toggle(void) {
  caps_locked = !caps_locked;
  digitalWrite(PIN_LED_CAPSLOCK, caps_locked);
}

//static uint8_t special_keys[] = {
//  KEY_LEFT_SLEEP,
//  KEY_VOLUME_UP,
//  KEY_VOLUME_DOWN,
//  KEY_MUSIC_PLAY,
//  KEY_MUSIC_NEXT,
//  KEY_MUSIC_PREV
//};
//
//static bool is_special_key(uint8_t k) {
//  size_t i;
//
//  for (i = 0; i < sizeof(special_keys); i++) {
//    if (k == special_keys[i]) {
//      return true;
//    }
//  }
//
//  return false;
//}

static inline void key_update_buffer(struct key_map* keymap, bool new_read) {
    unsigned int count;
    unsigned int pholder;

    keymap->buffer = keymap->buffer & ~(1U       << keymap->buffer_pos);
    keymap->buffer = keymap->buffer |  (new_read << keymap->buffer_pos);

    count = 0;
    pholder = keymap->buffer;

    while (pholder) {
        count += pholder & 1;
        pholder = pholder >> 1;
    }

    keymap->actual = count >= KEY_BUFFER_ACCEPT_TRUE;

    keymap->buffer_pos++;
    keymap->buffer_pos = keymap->buffer_pos & KEY_BUFFER_SIZE_FILER;
}

static struct char_holder Layout[NUMBER_OF_SEGS][KEYS_IN_SEGS] = {
  { // SEGMENT 0
    { def: KEY_ESC,           fn: '`',                fn_press: NULL,         fn_release: NULL },
    { def: 'w',               fn: NULL,               fn_press: NULL,         fn_release: NULL },
    { def: '4',               fn: KEY_F4,             fn_press: NULL,         fn_release: NULL },
    { def: '5',               fn: KEY_F5,             fn_press: NULL,         fn_release: NULL },
    { def: '7',               fn: KEY_F7,             fn_press: NULL,         fn_release: NULL },
    { def: '9',               fn: KEY_F9,             fn_press: NULL,         fn_release: NULL },
    { def: '-',               fn: KEY_F11,            fn_press: NULL,         fn_release: NULL },
    { def: KEY_BACKSPACE,     fn: NULL,               fn_press: NULL,         fn_release: NULL }
  },
  { // SEGMENT 1
    { def: '1',               fn: KEY_F1,             fn_press: NULL,         fn_release: NULL },
    { def: '3',               fn: KEY_F3,             fn_press: NULL,         fn_release: NULL },
    { def: 'r',               fn: NULL,               fn_press: NULL,         fn_release: NULL },
    { def: '6',               fn: KEY_F6,             fn_press: NULL,         fn_release: NULL },
    { def: '8',               fn: KEY_F8,             fn_press: NULL,         fn_release: NULL },
    { def: '0',               fn: KEY_F10,            fn_press: NULL,         fn_release: NULL },
    { def: '=',               fn: KEY_F12,            fn_press: NULL,         fn_release: NULL },
    { def: KEY_INSERT,        fn: KEY_PRINT_SCREEN,   fn_press: NULL,         fn_release: NULL }
  },
  { // SEGMENT 2
    { def: 'q',               fn: NULL,               fn_press: NULL,         fn_release: NULL },
    { def: 's',               fn: NULL,               fn_press: NULL,         fn_release: NULL },
    { def: 'f',               fn: NULL,               fn_press: NULL,         fn_release: NULL },
    { def: 'y',               fn: NULL,               fn_press: NULL,         fn_release: NULL },
    { def: 'i',               fn: NULL,               fn_press: NULL,         fn_release: NULL },
    { def: 'p',               fn: NULL,               fn_press: NULL,         fn_release: NULL },
    { def: ']',               fn: NULL,               fn_press: NULL,         fn_release: NULL },
    { def: KEY_DELETE,        fn: NULL,               fn_press: NULL,         fn_release: NULL }
  },
  { // SEGMENT 3
    { def: KEY_TAB,           fn: NULL,               fn_press: NULL,         fn_release: NULL },
    { def: '2',               fn: KEY_F2,             fn_press: NULL,         fn_release: NULL },
    { def: 'e',               fn: NULL,               fn_press: NULL,         fn_release: NULL },
    { def: 't',               fn: NULL,               fn_press: NULL,         fn_release: NULL },
    { def: 'u',               fn: NULL,               fn_press: NULL,         fn_release: NULL },
    { def: 'o',               fn: NULL,               fn_press: NULL,         fn_release: NULL },
    { def: '[',               fn: NULL,               fn_press: NULL,         fn_release: NULL },
    { def: '\\',              fn: NULL,               fn_press: NULL,         fn_release: NULL }
  },
  { // SEGMENT 4
    { def: KEY_LEFT_GUI,      fn: NULL,               fn_press: key_win_lock_toggle, fn_release: NULL }, // Left WIN
    { def: 'x',               fn: NULL,               fn_press: NULL,         fn_release: NULL },
    { def: 'v',               fn: NULL,               fn_press: NULL,         fn_release: NULL },
    { def: 'h',               fn: NULL,               fn_press: NULL,         fn_release: NULL },
    { def: 'k',               fn: NULL,               fn_press: NULL,         fn_release: NULL },
    { def: ';',               fn: KEY_MUSIC_PREV,     fn_press: NULL,         fn_release: NULL },
    { def: KEY_RIGHT_SHIFT,   fn: NULL,               fn_press: NULL,         fn_release: NULL },
    { def: KEY_HOME,          fn: NULL,               fn_press: NULL,         fn_release: NULL }
  },
  { // SEGMENT 5
    { def: KEY_CAPS_LOCK,     fn: NULL,               fn_press: NULL,         fn_release: NULL },
    { def: 'a',               fn: NULL,               fn_press: NULL,         fn_release: NULL },
    { def: 'd',               fn: NULL,               fn_press: NULL,         fn_release: NULL },
    { def: 'g',               fn: NULL,               fn_press: NULL,         fn_release: NULL },
    { def: 'j',               fn: NULL,               fn_press: NULL,         fn_release: NULL },
    { def: 'l',               fn: NULL,               fn_press: NULL,         fn_release: NULL },
    { def: '\'',              fn: KEY_MUSIC_NEXT,     fn_press: NULL,         fn_release: NULL },
    { def: KEY_RETURN,        fn: NULL,               fn_press: NULL,         fn_release: NULL }
  },
  { // SEGMENT 6
    { def: KEY_LEFT_CTRL,     fn: NULL,               fn_press: NULL,         fn_release: NULL },
    { def: KEY_LEFT_ALT,      fn: NULL,               fn_press: NULL,         fn_release: NULL },
    { def: ' ',               fn: NULL,               fn_press: NULL,         fn_release: NULL },
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

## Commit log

2023-07-22 init with keyboard files
    [BOM_JLCSMT.xlsx, case bottom display.ipt, case bottom.0008.ipt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]
2023-07-24 battery connectors with diodes. (Should be replaced to FETs before production)
    [keyboard.kicad_pcb, keyboard.kicad_sch]
2023-07-24 Remove unnecessary files and add pullups for arrow keys.
    [keyboard.kicad_pcb, keyboard.kicad_sch]
2023-07-25 This branch made for the Desktop App feature
    !!!NOT WORKING!!!
    [KBB.cpp, KBB.h, KBB.ino]
2023-07-26 Battery planning
    [battery_usb.kicad_sch, keyboard.kicad_sch]
2023-07-26 add board enable
2023-07-26 Added 3.3V
    [battery_usb.kicad_sch]
2023-07-27 usb hub wireing half
    [battery_usb.kicad_sch, keyboard.kicad_pcb]
2023-07-27 Implement USB Hub
    [battery_management.kicad_sch, battery_usb.kicad_sch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]
2023-07-27 shematic and pcb update
    [key_muxes.kicad_sch, keyboard.kicad_pcb, keyboard.kicad_sch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]
2023-07-29 I commit my case files.
    [KBB_Keyboard left.SLDPRT, KBB_Keyboard left.STL, KBB_Keyboard right.SLDPRT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]
2023-07-31 new versions and finalized wired version
    [battery_management.kicad_sch, battery_usb.kicad_sch, key_muxes.kicad_sch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]
2023-08-02 Added plate design
    [case_plate.0001.iam, case_plate.ipt, case_plate.stl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]
2023-08-03 Case design for version 0.1
    [case bottom display.ipt, case bottom.ipt, case bottom.stl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]
2023-08-03 Cut parts
    [case_in_one_p1.0001.ipt, case_in_one_p1.ipt, case_in_one_p1.stl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]
2023-08-04 Plate dising and key modifications
    [case_in_one_p2.0002.ipt, case_in_one_p2.0003.ipt, case_in_one_p2.stl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]
2023-08-04 Modify keys to correct locations and remove Serial calls
    [KBB.cpp, KBB.h, KBB.ino]
2023-08-04 led back
2023-08-13 New case
    [case_in_one_p1.0001.ipt, case_in_one_p1.0003.ipt, case_in_one_p1.ipt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]
2023-08-22 New inventor casings for better patent
    [case_in_one_full_remake.ipt, case_in_one_full_remake.stl, case_in_one_p1.ipt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]
2023-08-22 Remove unnececcary
    [case_in_one_p1.0003.ipt, case_in_one_p2.0004.ipt]
2023-12-21 Add key filtering for better typing
2024-02-24 Put keyboard project to CMakeLists.txt instead of arduino project
2024-02-24 Rearrange folder structure
    [KBB_Keyboard left.SLDPRT, KBB_Keyboard left.STL, KBB_Keyboard right.SLDPRT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]
